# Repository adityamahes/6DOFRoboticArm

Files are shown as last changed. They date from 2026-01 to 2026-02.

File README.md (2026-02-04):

# 6-DOF Robotic Manipulator (v1)

**A 6-Degree-of-Freedom robotic arm built from scratch to test custom Inverse Kinematics (IK) algorithms and real-time motion planning.**

## Motivation

The goal was not to assemble a kit, but to engineer the entire stack—from the mechanical CAD design to the low-level motor control firmware. The primary challenge was implementing a custom **Inverse Kinematics solver** to translate 3D Cartesian coordinates  into specific joint angles  in real-time.

Future iterations will serve as a hardware testbed for **Brain-Computer Interface (BCI)** integration, translating EEG signals into physical manipulation.

## Tech Stack

### Software

* **Inverse Kinematics Solver:** Python (NumPy/SciPy) for matrix transformations.
* **Visualization:** Matplotlib for real-time 3D simulation.
* **Firmware:** C++ (Arduino) for servo control and serial communication.
* **Communication:** PySerial (UART) for PC-to-Microcontroller data stream.

### Hardware

* **Controller:** Arduino Mega.
* **Actuators:** MG996R (High Torque)
* **Chassis:** Custom designed in SolidWorks, 3D printed in PLA/PETG.
* **Power:**  6V 1.5A PSU (Crucial for preventing brownouts).

## The Math (Inverse Kinematics)

This project uses [Geometric / Analytical / Numerical] methods to solve the IK problem.

Key challenges solved:

1. **Singularity Management:** Handling edge cases where the Jacobian determinant approaches zero (e.g., "gimbal lock" or full extension).
2. **Joint Limits:** Software-clamping angles to prevent physical self-collision.
3. **Coordinate Transformation:** Geometric transformation maps the end-effector to the base by summing link vectors via trigonometry for position and accumulating joint angles for orientation.

## Technical Challenges & Solutions

| Challenge | Solution |
| --- | --- |
| **PWM Jitter** | Servos were shaking due to signal noise. Implemented a low-pass filter in software and added capacitor smoothing on the power rail. |
| **Torque Sag** | The elbow joint struggled against gravity at full extension. Added a counterweight/spring assist (or upgraded motor) to compensate. |
| **Latency** | Serial communication lag caused "stuttering." Optimized the baud rate to 115200 and packed data into binary structs instead of parsing strings. |

## Future Roadmap

* [ ] **Gripper Upgrade:** Designing a 3-finger gripper inspired by the Tesla Optimus hand.
* [ ] **Computer Vision:** Integrating OpenCV to track objects for autonomous pick-and-place.
* [ ] **BCI Integration:** Interfacing with OpenBCI hardware to control the end-effector via SSVEP or Motor Imagery signals.

## Repository Structure

```bash
├── CAD/                 # SolidWorks/STL files for printing
├── Arduino Code/            # Arduino/C++ code for the controller
├── Kinematics/          # Python scripts for IK solver & Simulation
├── Docs/                # Denavit-Hartenberg parameter tables & schematics
└── README.md

```

## Setup & Usage

1. **Flash Firmware:** Upload the arduino code to the microcontroller.
2. **Install Dependencies:**
```bash
pip install numpy pyserial matplotlib

```

3. **Run Controller:**
```bash
python Kinematics/main_controller.py

```

---

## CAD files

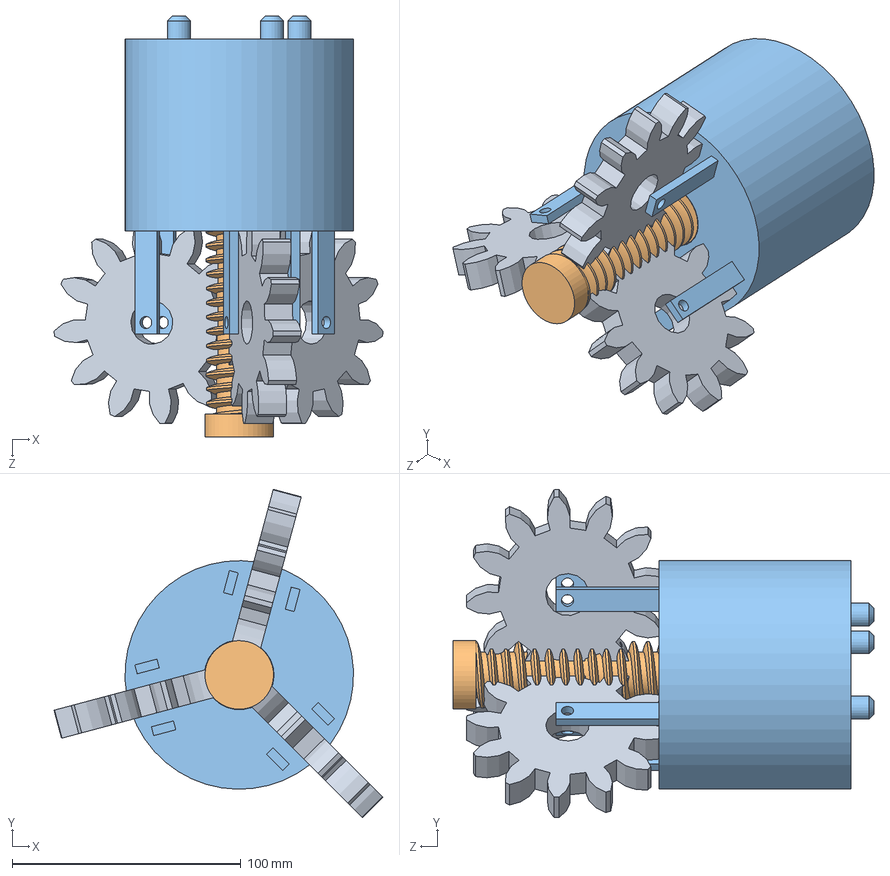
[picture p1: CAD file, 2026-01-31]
3FGripperCAD/Assem8.SLDASM
143.9 x 143.7 x 184.0 mm
worm
spur gear_am x 3

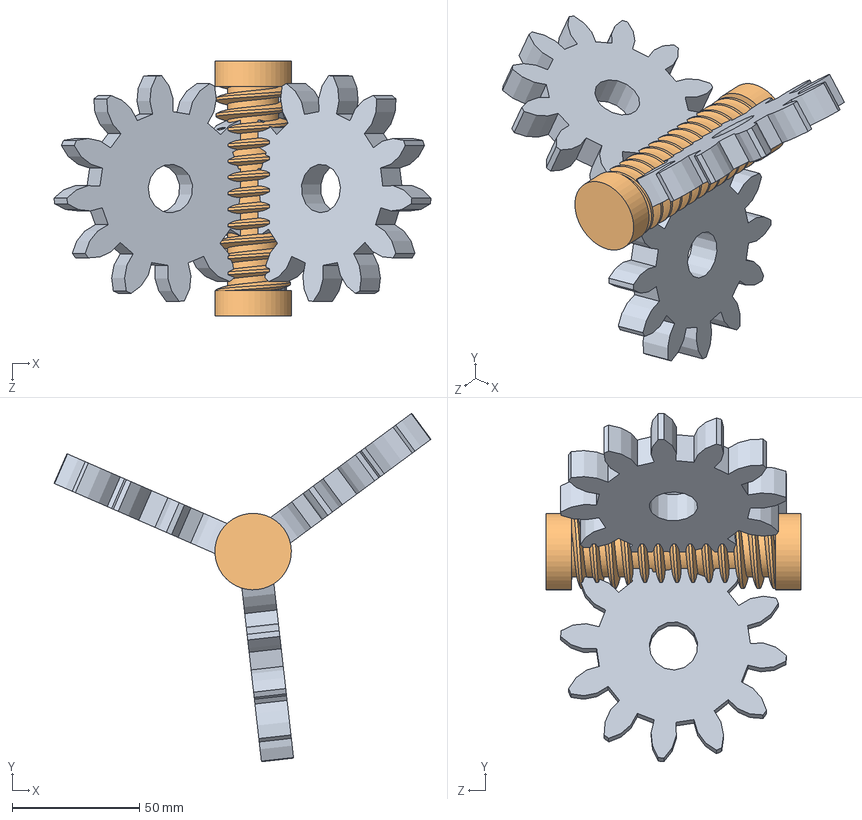
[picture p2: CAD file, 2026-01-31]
3FGripperCAD/Assem6.SLDASM
147.9 x 136.7 x 100.0 mm
worm
spur gear_am x 3

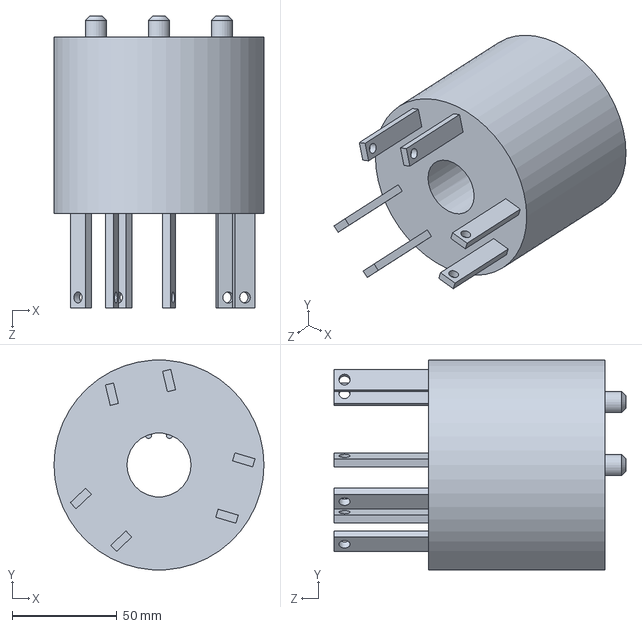
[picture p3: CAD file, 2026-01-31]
3FGripperCAD/Part9.SLDPRT
100.0 x 99.8 x 139.0 mm

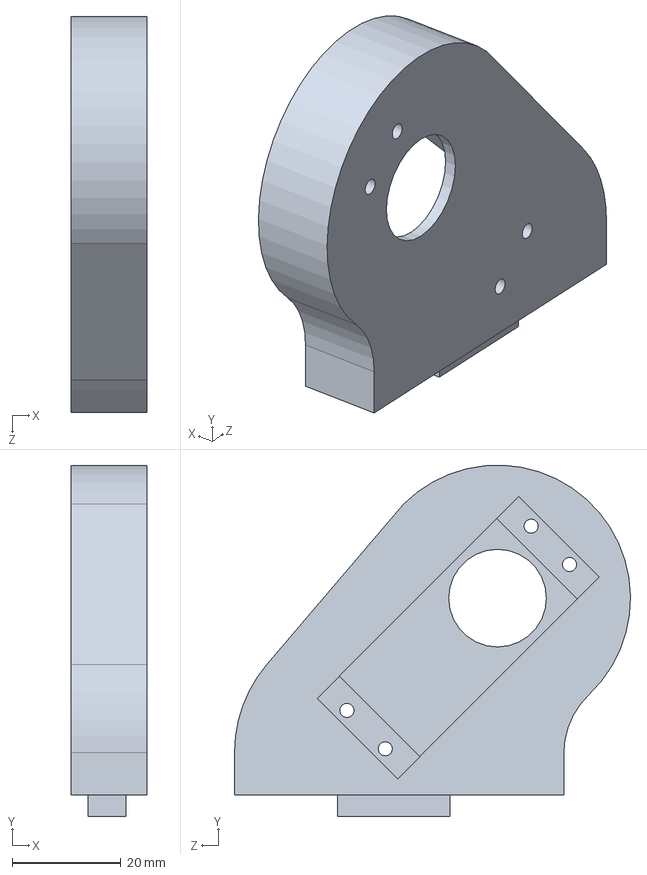
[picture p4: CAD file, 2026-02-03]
Optimus Body/Optimus Waist V2.SLDPRT
14.0 x 64.8 x 73.0 mm

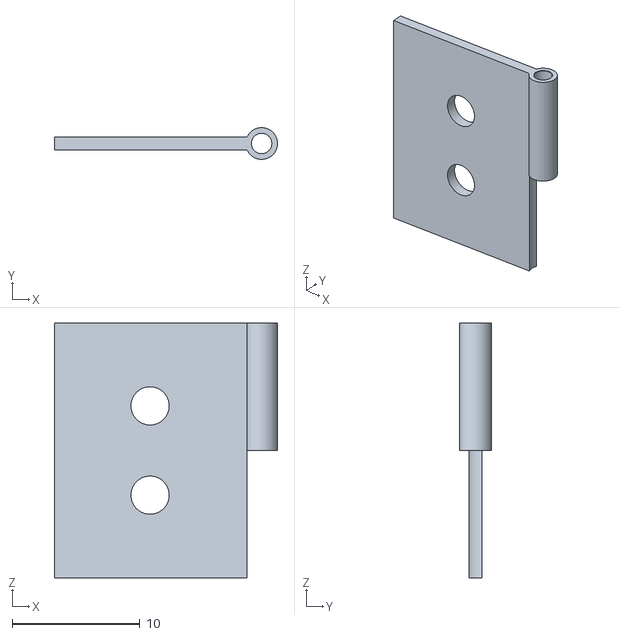
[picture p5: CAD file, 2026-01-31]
TeslaOptimusCAD/Hingeb.STL
17.5 x 2.50 x 20.0

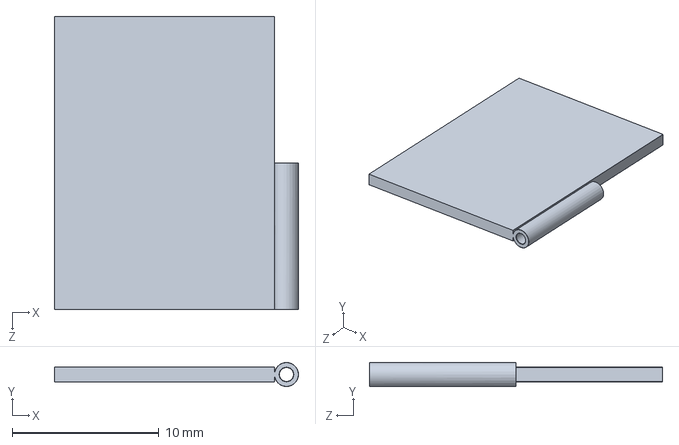
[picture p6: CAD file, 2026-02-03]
Optimus Body/Robot Hinge.SLDPRT
16.6 x 1.64 x 20.0 mm

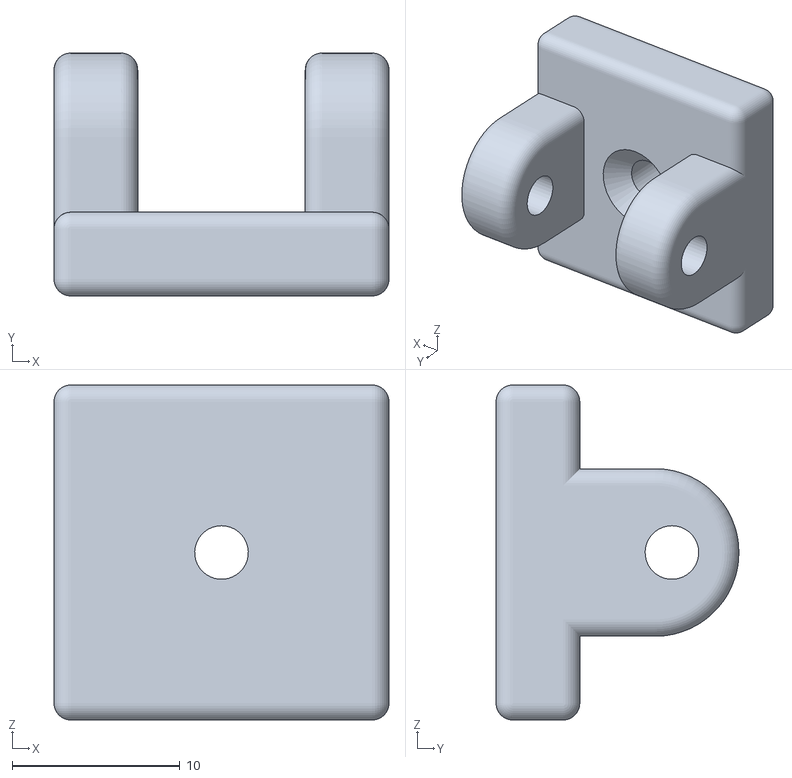
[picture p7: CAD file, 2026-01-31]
TeslaOptimusCAD/Spinninga.STL
20.0 x 14.5 x 20.0

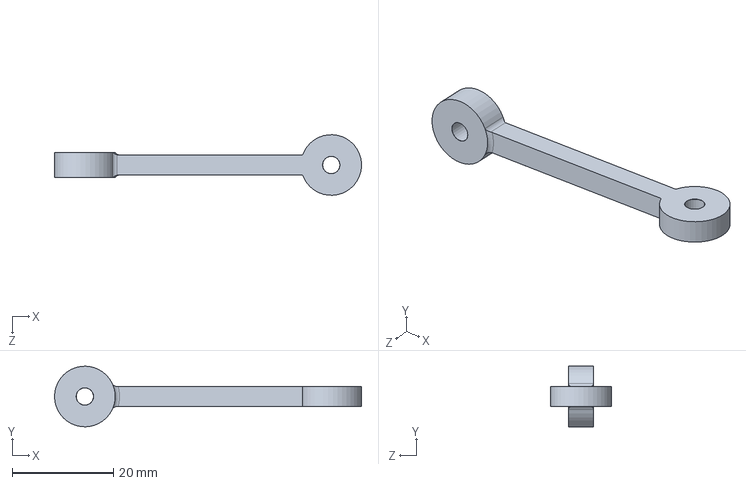
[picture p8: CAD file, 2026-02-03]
Optimus Body/Robot rod.SLDPRT
60.7 x 12.0 x 12.0 mm

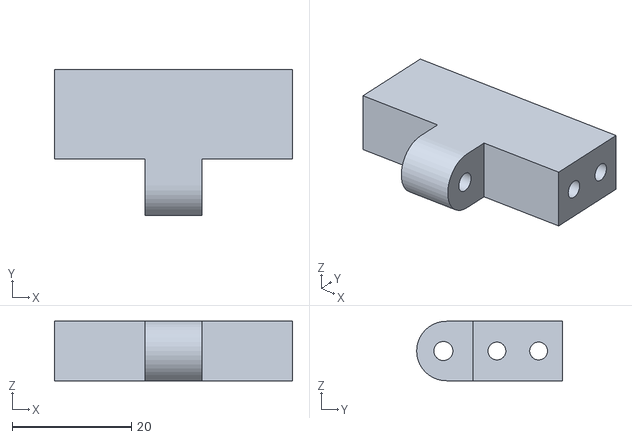
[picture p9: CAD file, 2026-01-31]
TeslaOptimusCAD/Spinningb.STL
40.0 x 24.5 x 10.0

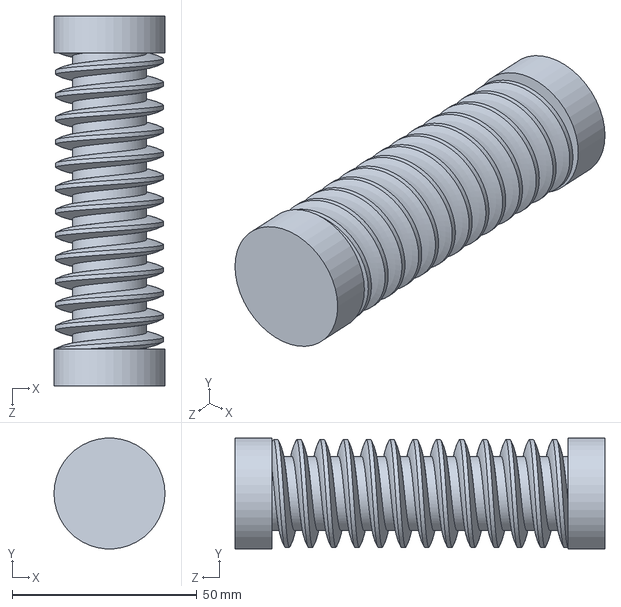
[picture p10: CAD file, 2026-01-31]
3FGripperCAD/worm.SLDPRT
30.0 x 29.9 x 100.0 mm

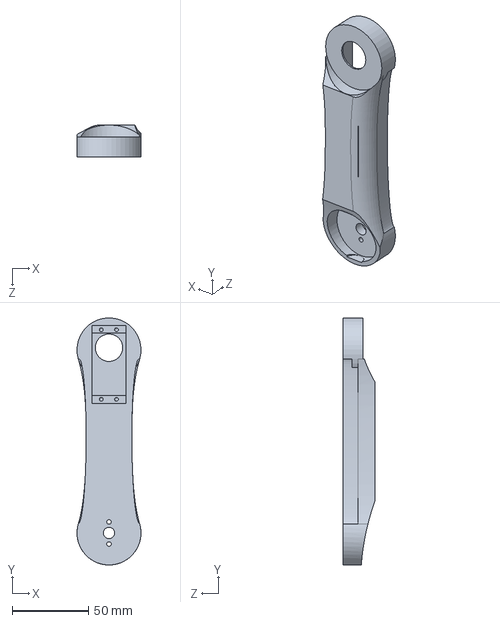
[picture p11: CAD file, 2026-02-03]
Optimus Body/Optimus Right Arm.SLDPRT
42.0 x 161.9 x 21.0 mm

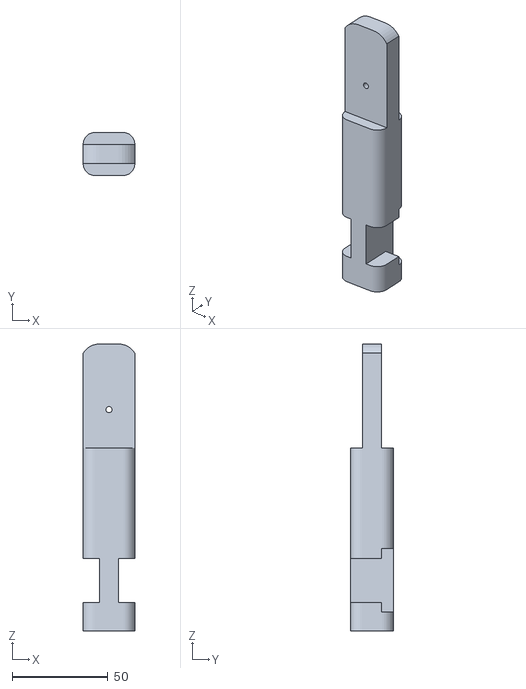
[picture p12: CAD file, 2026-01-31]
TeslaOptimusCAD/WristBase.STL
27.0 x 22.4 x 150.0

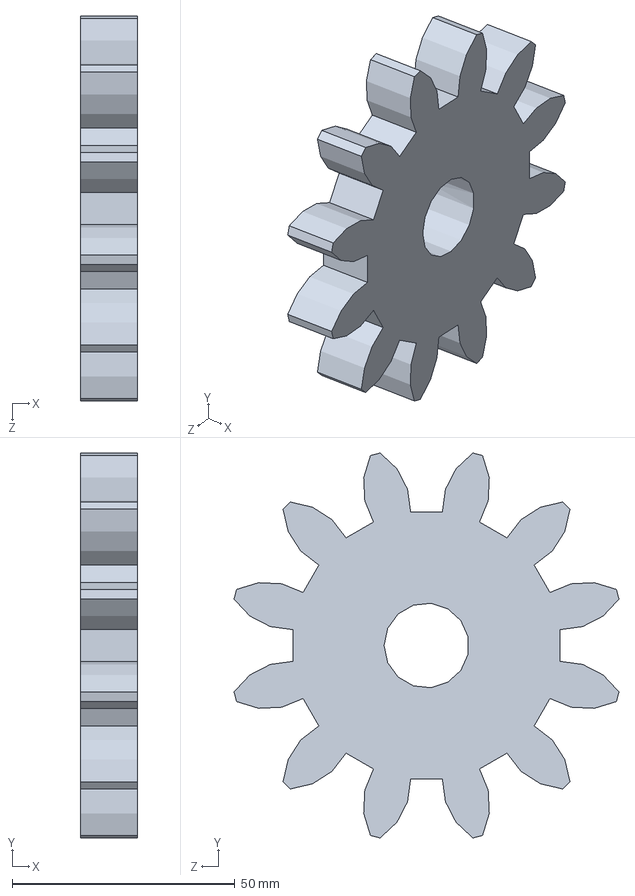
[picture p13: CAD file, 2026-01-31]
3FGripperCAD/spur gear_am.sldprt
12.7 x 86.4 x 86.4 mm

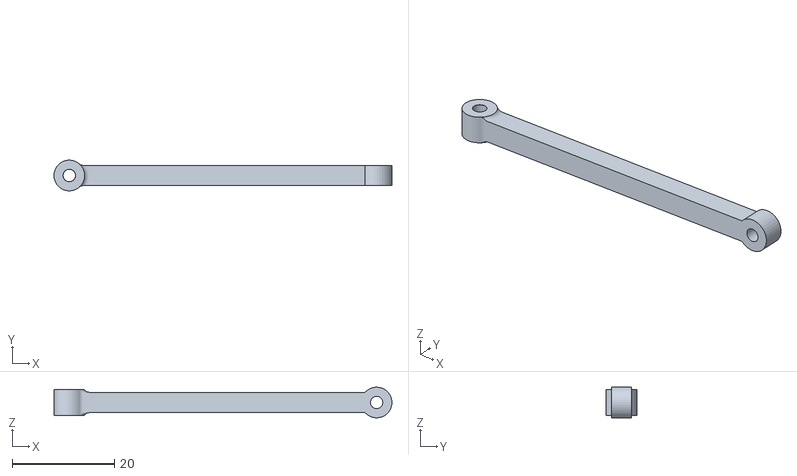
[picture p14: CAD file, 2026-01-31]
TeslaOptimusCAD/Rod.STL
66.0 x 5.99 x 6.00

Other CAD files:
Optimus Body/Servo Motor MG996R.SLDPRT
Optimus Body/Optimus Waist left v2.SLDPRT
TeslaOptimusCAD/Hingea.STL
Optimus Body/Base Cover Optimus v2.SLDPRT
Optimus Body/Optimus Arm #2 V2.SLDPRT
Optimus Body/Optimus Arm.SLDPRT
Optimus Body/Servo Motor Micro 9g.SLDPRT
Optimus Body/optimus base.SLDPRT

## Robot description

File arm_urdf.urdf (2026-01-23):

<?xml version="1.0"?>
<robot name="arm_robot">

  <material name="grey">
    <color rgba="0.5 0.5 0.5 1"/>
  </material>
  <material name="blue">
    <color rgba="0.2 0.2 0.8 1"/>
  </material>

  <link name="base_link">
    <visual>
      <origin xyz="0 0 0.026" rpy="0 0 0"/>
      <geometry>
        <cylinder length="0.052" radius="0.049"/>
      </geometry>
      <material name="grey"/>
    </visual>
  </link>

  <joint name="base_joint" type="revolute">
    <parent link="base_link"/>
    <child link="shoulder_link"/>
    <origin xyz="0 0 0.052" rpy="0 0 0"/>
    <axis xyz="0 0 1"/>
    <limit lower="-3.1415" upper="3.1415" effort="10" velocity="1.0"/>
  </joint>

  <link name="shoulder_link">
    <visual>
      <origin xyz="0.00875 0 0.018138" rpy="0 0 0"/>
      <geometry>
        <box size="0.035 0.06 0.036276"/>
      </geometry>
      <material name="grey"/>
    </visual>
  </link>

  <joint name="shoulder_joint" type="revolute">
    <parent link="shoulder_link"/>
    <child link="arm_1"/>
    <origin xyz="0.0175 0 0.036276" rpy="0 0 0"/>
    <axis xyz="0 1 0"/>
    <limit lower="-1.5708" upper="1.5708" effort="10" velocity="1.0"/>
  </joint>

  <link name="arm_1">
    <visual>
      <origin xyz="0 0 0.060725" rpy="0 0 0"/>
      <geometry>
        <box size="0.04 0.05 0.12145"/>
      </geometry>
      <material name="blue"/>
    </visual>
  </link>

  <joint name="elbow_joint" type="revolute">
    <parent link="arm_1"/>
    <child link="arm_2"/> 
    <origin xyz="0 0 0.12145" rpy="0 0 0"/>
    <axis xyz="0 1 0"/>
    <limit lower="-1.5708" upper="1.5708" effort="10" velocity="1.0"/>
  </joint>

  <link name="arm_2">
    <visual>
      <origin xyz="0 0 0.0910875" rpy="0 0 0"/>
      <geometry>
        <box size="0.035 0.045 0.182175"/>
      </geometry>
      <material name="grey"/>
    </visual>
  </link>

</robot>

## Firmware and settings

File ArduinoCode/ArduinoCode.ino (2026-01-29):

#include <Servo.h>
#include <math.h>

const int SERVO_PINS[6] = {3, 5, 6, 9, 10, 11};
const float L0 = 0.0175;
const float L1 = 0.088276;
const float L2 = 0.12145;
const float L3 = 0.182175;
const float BASE_MIN = -PI;
const float BASE_MAX = PI;
const float SHOULDER_MIN = -PI/2;
const float SHOULDER_MAX = PI/2;
const float ELBOW_MIN = -PI/2;
const float ELBOW_MAX = PI/2;
const float WRIST_MIN = -PI;
const float WRIST_MAX = PI;

class Joint {
private:
  Servo servo;
  int pin;
  float minAngle;
  float maxAngle;
  float currentAngle;
  
public:
  Joint(int servoPin, float minRad, float maxRad) 
    : pin(servoPin), minAngle(minRad), maxAngle(maxRad), currentAngle(0) {}
  
  void attach() {
    servo.attach(pin);
  }
  
  bool setAngle(float angleRad) {
    if (angleRad < minAngle || angleRad > maxAngle) {
      return false;
    }
    currentAngle = angleRad;
    int servoPos = radiansToServo(angleRad);
    servo.write(servoPos);
    return true;
  }
  
  float getAngle() const {
    return currentAngle;
  }
  
  float getMinAngle() const {
    return minAngle;
  }
  
  float getMaxAngle() const {
    return maxAngle;
  }
  
private:
  int radiansToServo(float angle) {
    angle = constrain(angle, minAngle, maxAngle);
    float range = maxAngle - minAngle;
    int servoPos = (int)((angle - minAngle) / range * 180.0);
    return constrain(servoPos, 0, 180);
  }
};

class KinematicsSolver {
private:
  float L0, L1, L2, L3;
  
public:
  KinematicsSolver(float link0, float link1, float link2, float link3) 
    : L0(link0), L1(link1), L2(link2), L3(link3) {}
  
  bool solveIK(float x, float y, float z, float& theta0, float& theta1, float& theta2,
               float baseMin, float baseMax, float shoulderMin, float shoulderMax, 
               float elbowMin, float elbowMax) {
    theta0 = atan2(y, x);
    
    if (theta0 < baseMin || theta0 > baseMax) {
      return false;
    }
    
    float r_xy = sqrt(x*x + y*y);
    float r = r_xy - L0;
    
    if (r < 0) {
      return false;
    }
    
    float z_adj = z - L1;
    float d = sqrt(r*r + z_adj*z_adj);
    
    if (d > (L2 + L3) || d < fabs(L2 - L3)) {
      return false;
    }
    
    float cos_theta2 = (d*d - L2*L2 - L3*L3) / (2 * L2 * L3);
    
    if (cos_theta2 < -1 || cos_theta2 > 1) {
      return false;
    }
    
    theta2 = atan2(-sqrt(1 - cos_theta2*cos_theta2), cos_theta2);
    
    float alpha = atan2(z_adj, r);
    float beta = atan2(L3 * sin(theta2), L2 + L3 * cos(theta2));
    theta1 = alpha - beta;
    
    if (theta1 < shoulderMin || theta1 > shoulderMax ||
        theta2 < elbowMin || theta2 > elbowMax) {
      return false;
    }
    
    return true;
  }
  
  void solveFK(float theta0, float theta1, float theta2, float& x, float& y, float& z) {
    float r = L2 * cos(theta1) + L3 * cos(theta1 + theta2);
    float r_total = r + L0;
    float z_local = L2 * sin(theta1) + L3 * sin(theta1 + theta2);
    
    x = r_total * cos(theta0);
    y = r_total * sin(theta0);
    z = z_local + L1;
  }
};

class RobotArm {
private:
  Joint joints[6];
  KinematicsSolver ikSolver;
  static const int NUM_JOINTS = 6;
  
public:
  RobotArm(const int pins[6], float L0, float L1, float L2, float L3)
    : joints{
        Joint(pins[0], BASE_MIN, BASE_MAX),
        Joint(pins[1], SHOULDER_MIN, SHOULDER_MAX),
        Joint(pins[2], ELBOW_MIN, ELBOW_MAX),
        Joint(pins[3], WRIST_MIN, WRIST_MAX),
        Joint(pins[4], WRIST_MIN, WRIST_MAX),
        Joint(pins[5], WRIST_MIN, WRIST_MAX)
      },
      ikSolver(L0, L1, L2, L3) {}
  
  void initialize() {
    for (int i = 0; i < NUM_JOINTS; i++) {
      joints[i].attach();
    }
    moveToHome();
  }
  
  void moveToHome() {
    for (int i = 0; i < NUM_JOINTS; i++) {
      joints[i].setAngle(0);
    }
  }
  
  bool moveToPosition(float x, float y, float z, float roll, float pitch, float yaw) {
    float theta0, theta1, theta2;
    
    bool success = ikSolver.solveIK(x, y, z, theta0, theta1, theta2,
                                     joints[0].getMinAngle(), joints[0].getMaxAngle(),
                                     joints[1].getMinAngle(), joints[1].getMaxAngle(),
                                     joints[2].getMinAngle(), joints[2].getMaxAngle());
    
    if (!success) {
      return false;
    }
    
    joints[0].setAngle(theta0);
    joints[1].setAngle(theta1);
    joints[2].setAngle(theta2);
    joints[3].setAngle(roll);
    joints[4].setAngle(pitch);
    joints[5].setAngle(yaw);
    
    return true;
  }
  
  void getJointAngles(float angles[6]) const {
    for (int i = 0; i < NUM_JOINTS; i++) {
      angles[i] = joints[i].getAngle();
    }
  }
  
  void getCurrentPosition(float& x, float& y, float& z) {
    ikSolver.solveFK(joints[0].getAngle(), joints[1].getAngle(), 
                     joints[2].getAngle(), x, y, z);
  }
  
  void printStatus(float x, float y, float z) const {
    Serial.print("Target: (");
    Serial.print(x, 3); Serial.print(", ");
    Serial.print(y, 3); Serial.print(", ");
    Serial.print(z, 3); Serial.println(")");
    
    Serial.print("Angles: [");
    for (int i = 0; i < NUM_JOINTS; i++) {
      Serial.print(joints[i].getAngle(), 3);
      if (i < NUM_JOINTS - 1) Serial.print(", ");
    }
    Serial.println("]");
  }
};

class SerialParser {
public:
  static bool parseCommand(String input, float values[6]) {
    int lastComma = -1;
    
    for (int i = 0; i < 6; i++) {
      int nextComma = input.indexOf(',', lastComma + 1);
      if (nextComma == -1 && i < 5) return false;
      
      String valueStr;
      if (nextComma == -1) {
        valueStr = input.substring(lastComma + 1);
      } else {
        valueStr = input.substring(lastComma + 1, nextComma);
      }
      
      values[i] = valueStr.toFloat();
      lastComma = nextComma;
    }
    
    return true;
  }
};

RobotArm robotArm(SERVO_PINS, L0, L1, L2, L3);

void setup() {
  Serial.begin(115200);
  robotArm.initialize();
  Serial.println("6DOF Robot Arm Ready");
  Serial.println("Format: x,y,z,roll,pitch,yaw");
  Serial.println("Position in meters, angles in radians");
}

void loop() {
  if (Serial.available() > 0) {
    String input = Serial.readStringUntil('\n');
    input.trim();
    
    float values[6];
    if (SerialParser::parseCommand(input, values)) {
      float x = values[0];
      float y = values[1];
      float z = values[2];
      float roll = values[3];
      float pitch = values[4];
      float yaw = values[5];
      
      if (robotArm.moveToPosition(x, y, z, roll, pitch, yaw)) {
        robotArm.printStatus(x, y, z);
      } else {
        Serial.println("ERROR: Position unreachable");
      }
    } else {
      Serial.println("ERROR: Invalid input format");
    }
  }
}

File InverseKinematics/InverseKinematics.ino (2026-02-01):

#include <Servo.h>

const int PIN_BASE      = 3;
const int PIN_SHOULDER1  = 6;
const int PIN_SHOULDER2  = 7;
const int PIN_ELBOW1     = 9;
const int PIN_ELBOW2     = 11; 
const int PIN_WRIST      = 12;

Servo base, shoulder1, shoulder2, elbow1, elbow2, wrist;

void setup() {
  Serial.begin(115200);

  base.attach(PIN_BASE);
  shoulder1.attach(PIN_SHOULDER1);
  shoulder2.attach(PIN_SHOULDER2);
  elbow1.attach(PIN_ELBOW1);
  elbow2.attach(PIN_ELBOW2);
  wrist.attach(PIN_WRIST);

}

void loop() {
  if (Serial.available() > 0) {
    String data = Serial.readStringUntil('\n');
    
    int bIdx = data.indexOf('B');
    int sIdx = data.indexOf('S');
    int eIdx = data.indexOf('E');
    
    if (bIdx != -1 && sIdx != -1 && eIdx != -1) {
      int bVal = data.substring(bIdx + 1, data.indexOf(',', bIdx)).toInt();
      int sVal = data.substring(sIdx + 1, data.indexOf(',', sIdx)).toInt();
      int eVal = data.substring(eIdx + 1).toInt();

      base.write(constrain(bVal, 0, 180));
      shoulder1.write(constrain(sVal, 0, 180));
      shoulder2.write(constrain(180 - sVal, 0, 180)); 
      elbow1.write(constrain(eVal, 0, 180));
      elbow2.write(constrain(180 - eVal, 0, 180));
      
      Serial.print("ACK:B"); Serial.print(bVal);
      Serial.print("S"); Serial.print(sVal);
      Serial.print("E"); Serial.println(eVal);
    }
  }
}

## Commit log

2026-01-23 Added Datasend script to send IK data to arduino. Removed Jupyter Notebook.
    [arm_urdf.urdf]
2026-01-29 Refactor servo control to use radians and group arrays
    Replaces individual servo objects with grouped arrays for more scalable control. Adds a writeRadians() function to convert radians to servo degrees, constrains input to safe ranges, and updates loop to demonstrate sweeping motion. Serial output added for debugging and initialization message.
    [ArduinoCode.ino]
2026-01-29 Add 6DOF robot arm control and random position generator
    Refactored ArduinoCode.ino to implement a 6DOF robot arm with kinematics, serial command parsing, and status reporting. Added randompos.py to generate random reachable positions for the arm. Added a 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
2026-01-31 Add 3D robot arm control and workspace visualization
    Added Arduino code for inverse kinematics control (InverseKinematics.ino), a Python script for interactive 3D robot arm control and serial communication (three_dimension_datasend.py), and refactored 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
2026-01-31 Clean up code and move Arduino file to Legacy folder
    Removed unnecessary comments and shebangs from Python files for clarity. Moved ArduinoCode.ino to the Legacy directory to better organize legacy code.
2026-01-31 Add new CAD and STL files for 3FGripper and TeslaOptimus
    Added assembly and part files for 3FGripperCAD, including Assem6, Assem8, Part9, spur gear, and worm. Also added STL files for TeslaOptimusCAD components: Hingea, Hingeb, Rod, Spinninga, Spinningb, a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
    [Assem6.SLDASM, Assem8.SLDASM, Hingea.STL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]
2026-02-03 Adding Body of Robotic Arm
    [Base Cover Optimus v2.SLDPRT, Optimus Arm #2 V2.SLDPRT, Optimus Arm.SLDPRT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]
